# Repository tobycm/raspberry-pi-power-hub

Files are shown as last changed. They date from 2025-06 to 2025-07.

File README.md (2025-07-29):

# RP2040 + CYPD3177 Power Hub

one port (usb c) to rule them all!!! this board is designed to take a single USB-C input and negociate for your power needs. it can output 5v, 9v, 12v, or 20v at up to 3A. the usb c port is also connected to a RP2040 if you want more processing with the CYPD3177 through HPI.

## 3D render

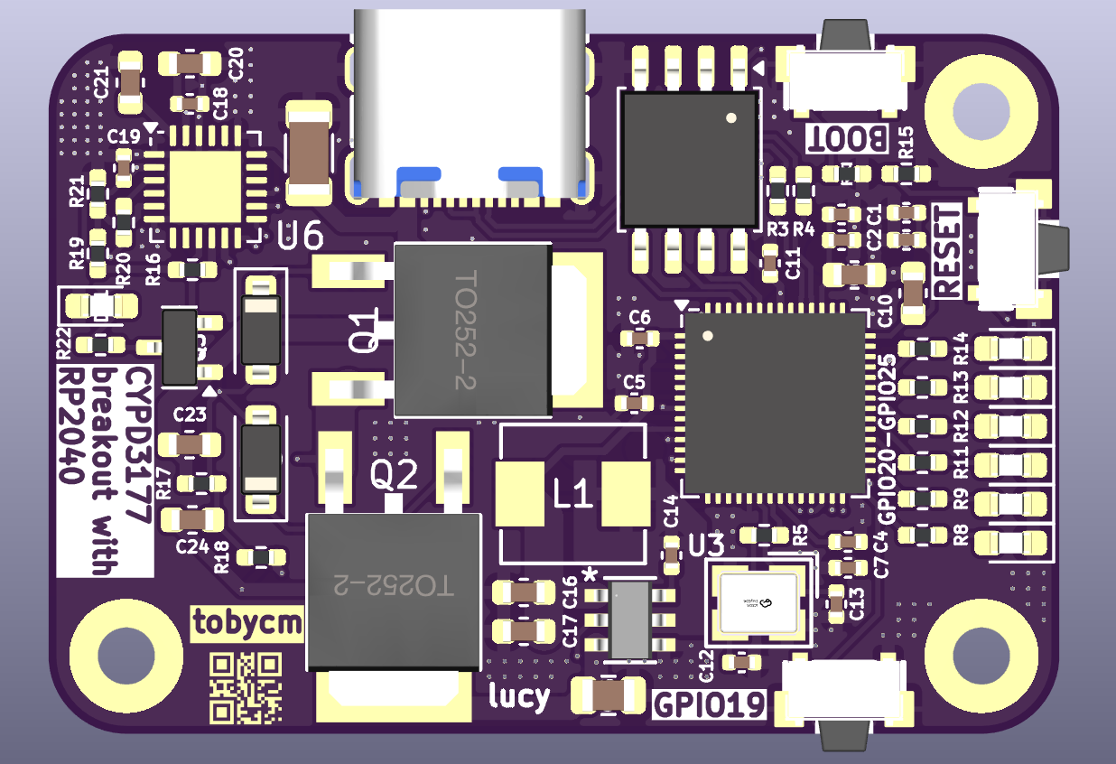
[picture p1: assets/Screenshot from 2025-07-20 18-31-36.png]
front


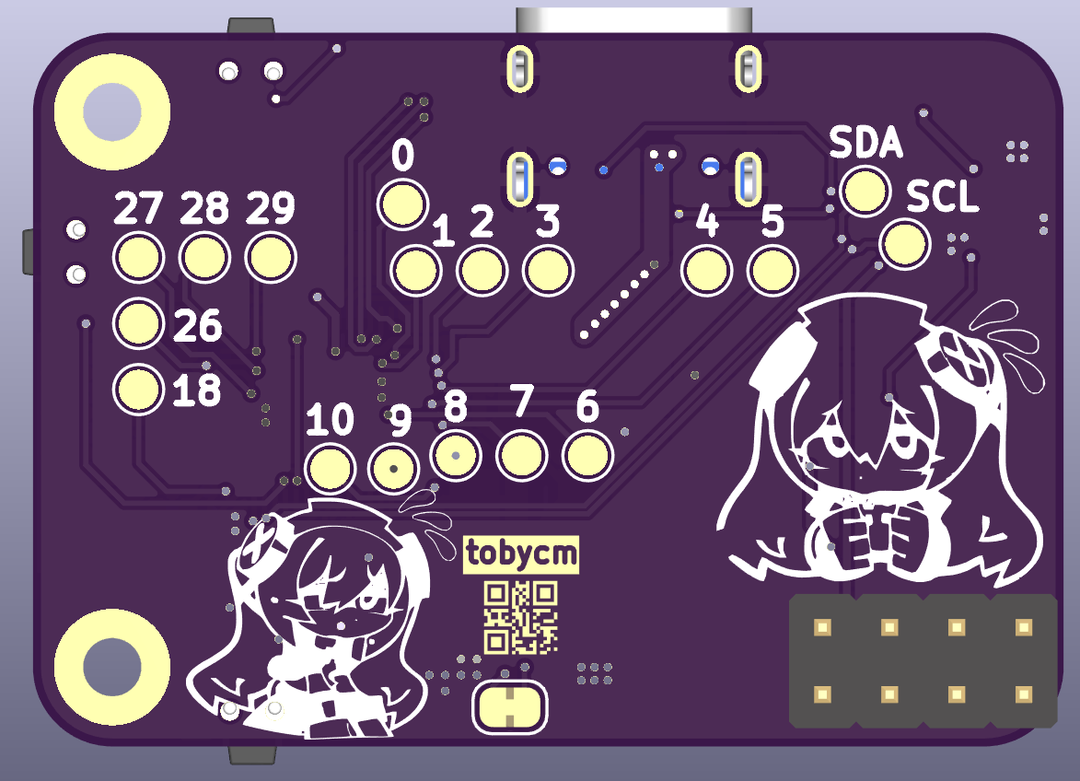
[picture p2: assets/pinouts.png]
back


## BOM

| Part Name | Quantity | Link |
| :--- | :---: | :--- |
| PCB | 1 | [JLCPCB](https://jlcpcb.com) |
| Stencil | 1 | [JLCPCB](https://jlcpcb.com) |
| RP2040 | 1 | [C2040](https://lcsc.com/product-detail/C2040.html) |
| CYPD3177-24LQ | 1 | [C5904158](https://lcsc.com/product-detail/C5904158.html) |
| W25Q32JVSS | 1 | [C82344](https://lcsc.com/product-detail/C82344.html) |
| GT-USB-7010AN | 1 | [C963370](https://lcsc.com/product-detail/C963370.html) |
| ABM8-272-T3\_C20625731 | 1 | [C20625731](https://lcsc.com/product-detail/C20625731.html) |
| TS24CA | 3 | [C393942](https://lcsc.com/product-detail/C393942.html) |
| AP63203WU-7 | 1 | [C780769](https://lcsc.com/product-detail/C780769.html) |
| Zener Diode | 2 | [C82088](https://lcsc.com/product-detail/C82088.html) |
| NPN | 1 | [C5338312](https://lcsc.com/product-detail/C5338312.html) |
| AOD409-HXY | 2 | [C6285771](https://lcsc.com/product-detail/C6285771.html) |
| Green Led | 2 | [C7496818](https://lcsc.com/product-detail/C7496818.html) |
| Amber Led | 2 | [C165983](https://lcsc.com/product-detail/C165983.html) |
| Red Led | 3 | [C965799](https://lcsc.com/product-detail/C965799.html) |
| 18pF | 2 | [C106202](https://lcsc.com/product-detail/C106202.html) |
| 100nF | 12 | [C60474](https://lcsc.com/product-detail/C60474.html) |
| 10uF | 3 | [C2762594](https://lcsc.com/product-detail/C2762594.html) |
| 1uF | 6 | [C1592](https://lcsc.com/product-detail/C1592.html) |
| 4.7uF | 1 | [C51205](https://lcsc.com/product-detail/C51205.html) |
| 4.7uH | 1 | [C41413058](https://lcsc.com/product-detail/C41413058.html) |
| 470ohm | 7 | [C25117](https://lcsc.com/product-detail/C25117.html) |
| 49.9kohm | 1 | [C25897](https://lcsc.com/product-detail/C25897.html) |
| 4.7kohm | 1 | [C25900](https://lcsc.com/product-detail/C25900.html) |
| 5.1kohm | 1 | [C25905](https://lcsc.com/product-detail/C25905.html) |
| 10kohm | 1 | [C60490](https://lcsc.com/product-detail/C60490.html) |
| 1kohm | 5 | [C106235](https://lcsc.com/product-detail/C106235.html) |
| 27ohm | 2 | [C138021](https://lcsc.com/product-detail/C138021.html) |
| Pin Headers | 1 | [C7501275](https://lcsc.com/product-detail/C7501275.html) |
| | |
| Total cost | 74.24 USD LCSC + 13.98 USD JLCPCB = 88.22 USD | |
| Soldering paste (cheaper than PCBA) | 1 | https://amazon.ca/dp/B0BLSJQPR6 |
| Total cost with soldering paste | 88.22 USD + 19.59 CAD = 102.43 USD | |

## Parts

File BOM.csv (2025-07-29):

Part Name | Quantity | Link
PCB | 1 | https://jlcpcb.com
Stencil | 1 | https://jlcpcb.com
RP2040 | 1 | https://lcsc.com/product-detail/C2040.html
CYPD3177-24LQ | 1 | https://lcsc.com/product-detail/C5904158.html
W25Q32JVSS | 1 | https://lcsc.com/product-detail/C82344.html
GT-USB-7010AN | 1 | https://lcsc.com/product-detail/C963370.html
ABM8-272-T3_C20625731 | 1 | https://lcsc.com/product-detail/C20625731.html
TS24CA | 3 | https://lcsc.com/product-detail/C393942.html
AP63203WU-7 | 1 | https://lcsc.com/product-detail/C780769.html
Zener Diode | 2 | https://lcsc.com/product-detail/C82088.html
NPN | 1 | https://lcsc.com/product-detail/C5338312.html
AOD409-HXY | 2 | https://lcsc.com/product-detail/C6285771.html
Green Led | 2 | https://lcsc.com/product-detail/C7496818.html
Amber Led | 2 | https://lcsc.com/product-detail/C165983.html
Red Led | 3 | https://lcsc.com/product-detail/C965799.html
18pF | 2 | https://lcsc.com/product-detail/C106202.html
100nF | 12 | https://lcsc.com/product-detail/C60474.html
10uF | 3 | https://lcsc.com/product-detail/C2762594.html
1uF | 6 | https://lcsc.com/product-detail/C1592.html
4.7uF | 1 | https://lcsc.com/product-detail/C51205.html
4.7uH | 1 | https://lcsc.com/product-detail/C41413058.html
470ohm | 7 | https://lcsc.com/product-detail/C25117.html
49.9kohm | 1 | https://lcsc.com/product-detail/C25897.html
4.7kohm | 1 | https://lcsc.com/product-detail/C25900.html
5.1kohm | 1 | https://lcsc.com/product-detail/C25905.html
10kohm | 1 | https://lcsc.com/product-detail/C60490.html
1kohm | 5 | https://lcsc.com/product-detail/C106235.html
27ohm | 2 | https://lcsc.com/product-detail/C138021.html
Pin Headers | 1 | https://lcsc.com/product-detail/C7501275.html

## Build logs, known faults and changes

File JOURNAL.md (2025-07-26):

---
author: tobycm
created_at: "2025-06-25"
description: a usb c power hub to power all of my raspberry pis (and other usb c devices!)
title: Raspberry Pi Power Hub
---

# Raspberry Pi Power Hub

## Jun 25, 2025 | 12:00 - 16:00 | Init

since i made devices with usb c pd stuff before, im going with cypd3175 and cypd3177 ICs for this :3

https://g.co/gemini/share/f052dd489182

i love gemini, lots of good researching and i can just compare and decide

after lots of consulting, i ended up with:

- 4 cypd3175 ics, for a total of 4 usb c and 4 usb a ports
- 1 cypd3177 ic
- 1 rp2040 ic for the main brain of the device 🔥🔥🔥

time to research for parts on lcsc, and wire them up in kicad

- usb c receptacle: [https://lcsc.com/product-detail/USB-Connectors_G-Switch-GT-USB-7010AN_C963370.html](https://lcsc.com/product-detail/USB-Connectors_G-Switch-GT-USB-7010AN_C963370.html)
- cypd3175: [https://lcsc.com/product-detail/USB-Converters_Infineon-Cypress-Semicon-CYPD3175-24LQXQT_C2952419.html](https://lcsc.com/product-detail/USB-Converters_Infineon-Cypress-Semicon-CYPD3175-24LQXQT_C2952419.html)
- cypd3177: [https://lcsc.com/product-detail/Power-Management-Specialized_Infineon-Technologies-CYPD3177-24LQXQT_C5904158.html](https://lcsc.com/product-detail/Power-Management-Specialized_Infineon-Technologies-CYPD3177-24LQXQT_C5904158.html)
- buck converter: [https://lcsc.com/product-detail/DC-DC-Converters_Tokmas-TPS54561DPRR-TOKMAS_C7589231.html](https://lcsc.com/product-detail/DC-DC-Converters_Tokmas-TPS54561DPRR-TOKMAS_C7589231.html)
- rp2040: [https://lcsc.com/product-detail/Microcontrollers-MCU-MPU-SOC_Raspberry-Pi-RP2040_C2040.html](https://lcsc.com/product-detail/Microcontrollers-MCU-MPU-SOC_Raspberry-Pi-RP2040_C2040.html)

## 21:00 - 22:50 | copied rp2040 wiring from previous board

with the new diode and no more latching button xd.

lots of time spent on finding parts on LCSC

## Jun 29, 2025 | 17:15 - 21:45 | wiring up cypd3177 and fix up rp2040

the datasheet reference schematic is the best place to start, as they have values that the manufacturer tested and recommends.

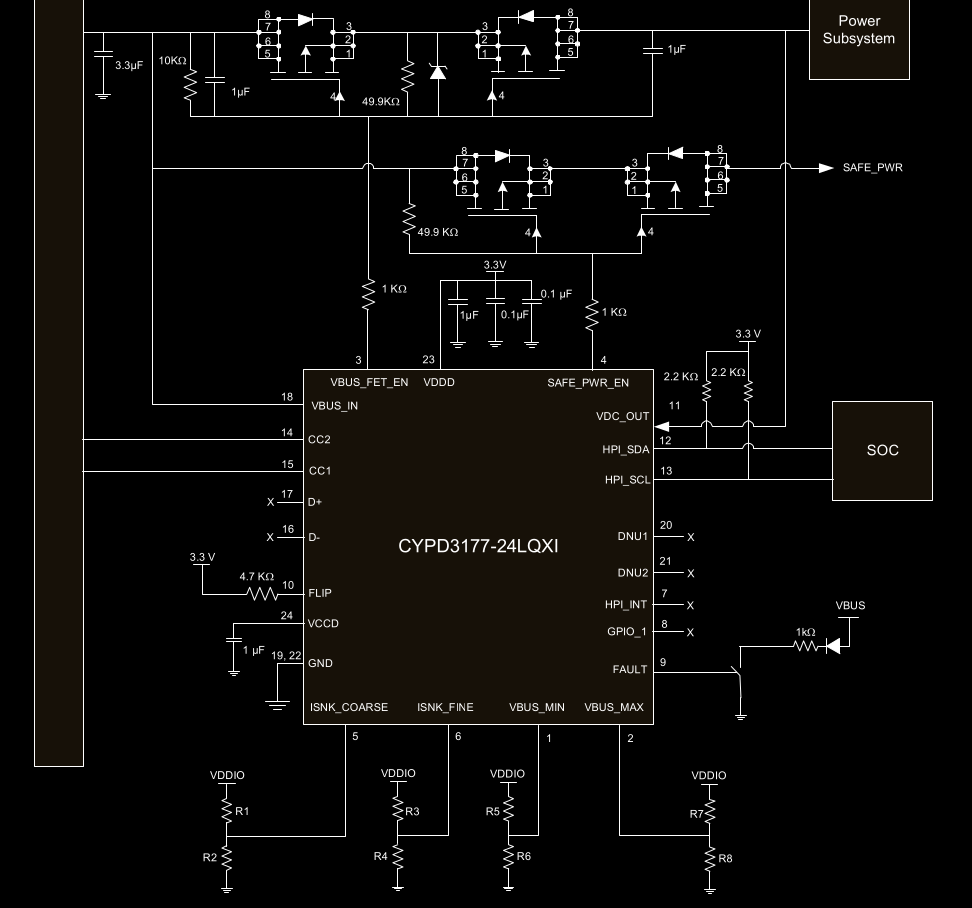
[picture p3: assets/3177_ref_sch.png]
datasheet reference schematic


after some questions and answers with Google Gemini, i learned that:

- the 2 mosfets facing each other are for reverse current protection, if this device is disconnected from the power source, it will not allow current to flow back into the power source, causing undefined behavior.
- safe_pwr always provides 5V, so that is nice to power microcontrollers and other devices that need 5V always on.
- table 2, 3, and 4 in the datasheet helps with choosing resistor values to set the desired voltage range and min current limit.

after a bit more chatting with Google Gemini:

- trying to optimize for efficiency: we went with a better buck converter than the XXL1509-5.0 with 83% for a Silergy brand buck converter, which has ~92% efficiency. a lot better.

because the cypd3175 can support an additional 5V usb output, i will supply 2 type a port with the Silergy 6A 5V buck converter

too much shopping, i should start wiring this up in kicad 💀

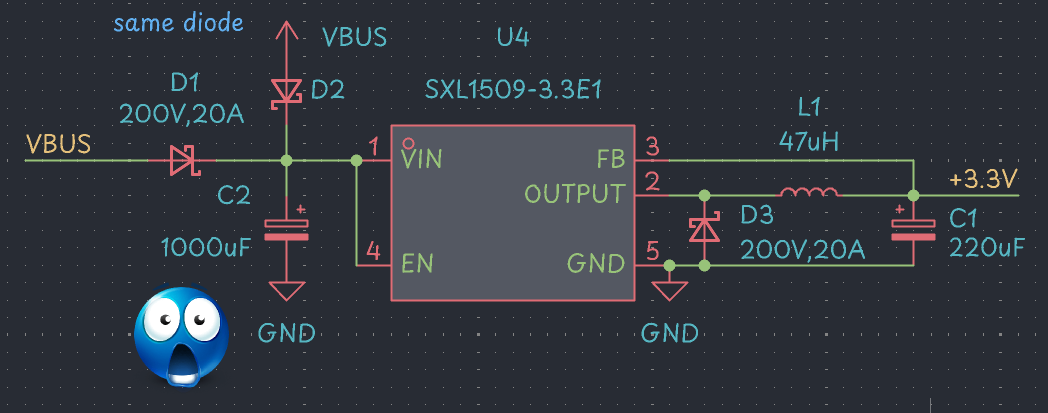
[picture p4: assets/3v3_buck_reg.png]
peak schematic


literally peak

## Jul 19, 2025 | 16:00 - 20:00 | finishing wiring up cypd3177

small life update: i got a new job :D downside is i have less time to work on this project :C

apparently lots of MOSFETs have max Vgs of 20V, so i had to find a zener diode to clamp the gate voltage to 18V, so that the MOSFETs don't get damaged.

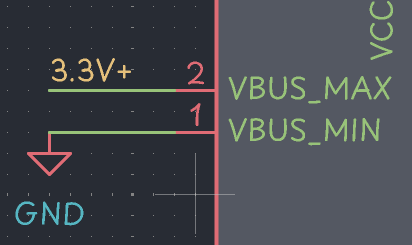
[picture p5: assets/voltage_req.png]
requesting 5V min and 20V max


to request 5V min and 20V max

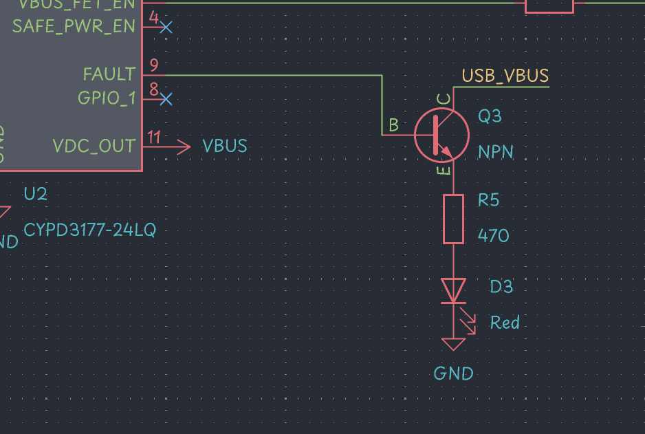
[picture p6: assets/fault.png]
fault led


added a fault indicator LED :D

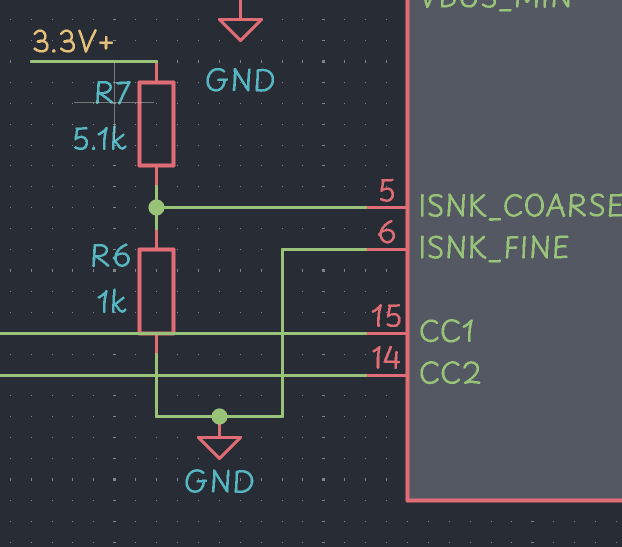
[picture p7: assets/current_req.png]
current request setup


to request at least 1A of current :D

## Jul 20, 2025 | 12:00 - 18:00 | laying out the board

i think i will make smaller cypd3175 modules, so this board will only have the cypd3177 and rp2040, and the buck converter for 3.3V

front 3d
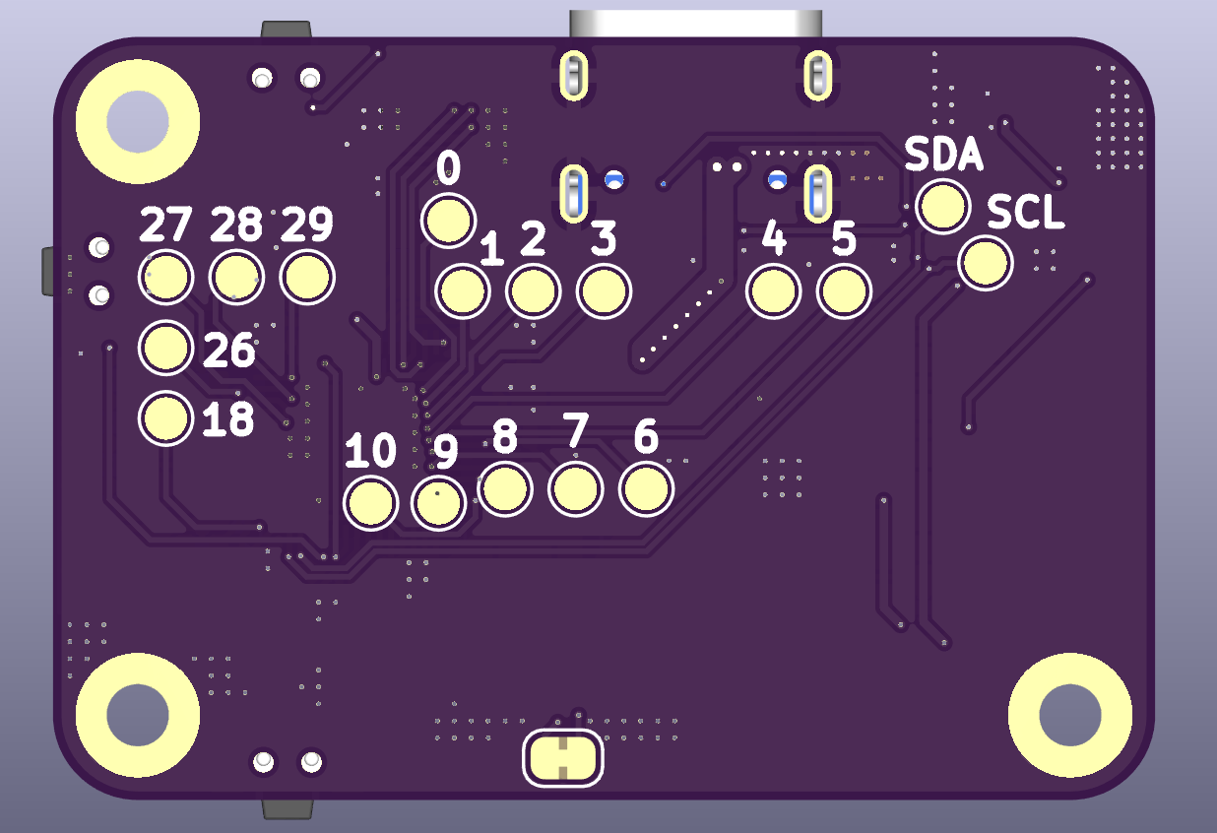
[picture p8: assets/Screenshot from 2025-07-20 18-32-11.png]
back 3d


FINALLY DONE WOOHOO! time to add a bunch of art and make it look nice :D

## Jul 26, 2025 | 13:20 - 15:00 | im cooked

i just realized that my via size is too small, so i have to fix all of that 😭😭😭😭😭😭

drc

oof

also i forgot that this is meant to be kinda like a breakout, and i forgot to breakout the power outputs 💀💀

good drc

lets gooooooooo

pinouts

pinouts added too! done!

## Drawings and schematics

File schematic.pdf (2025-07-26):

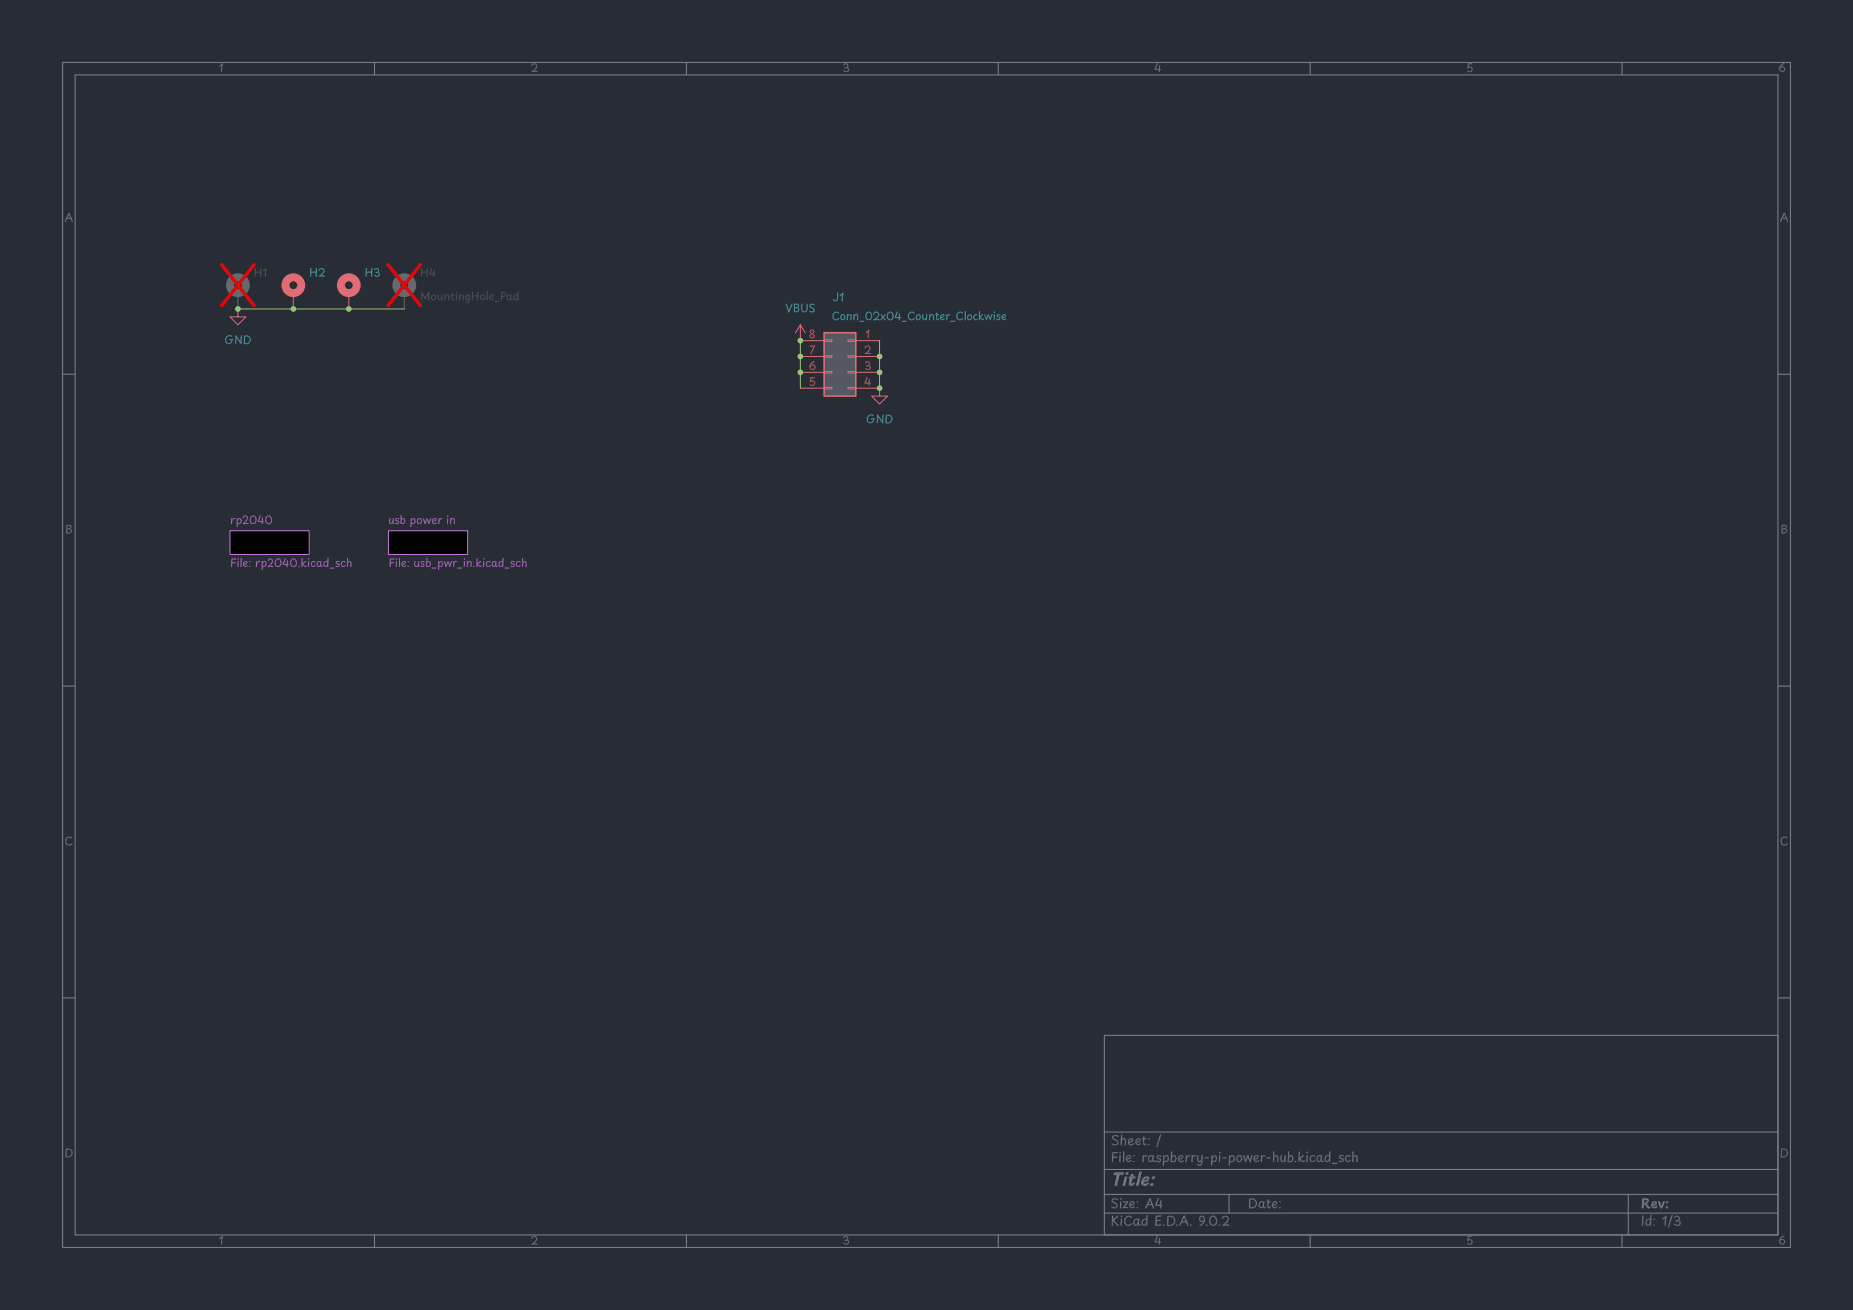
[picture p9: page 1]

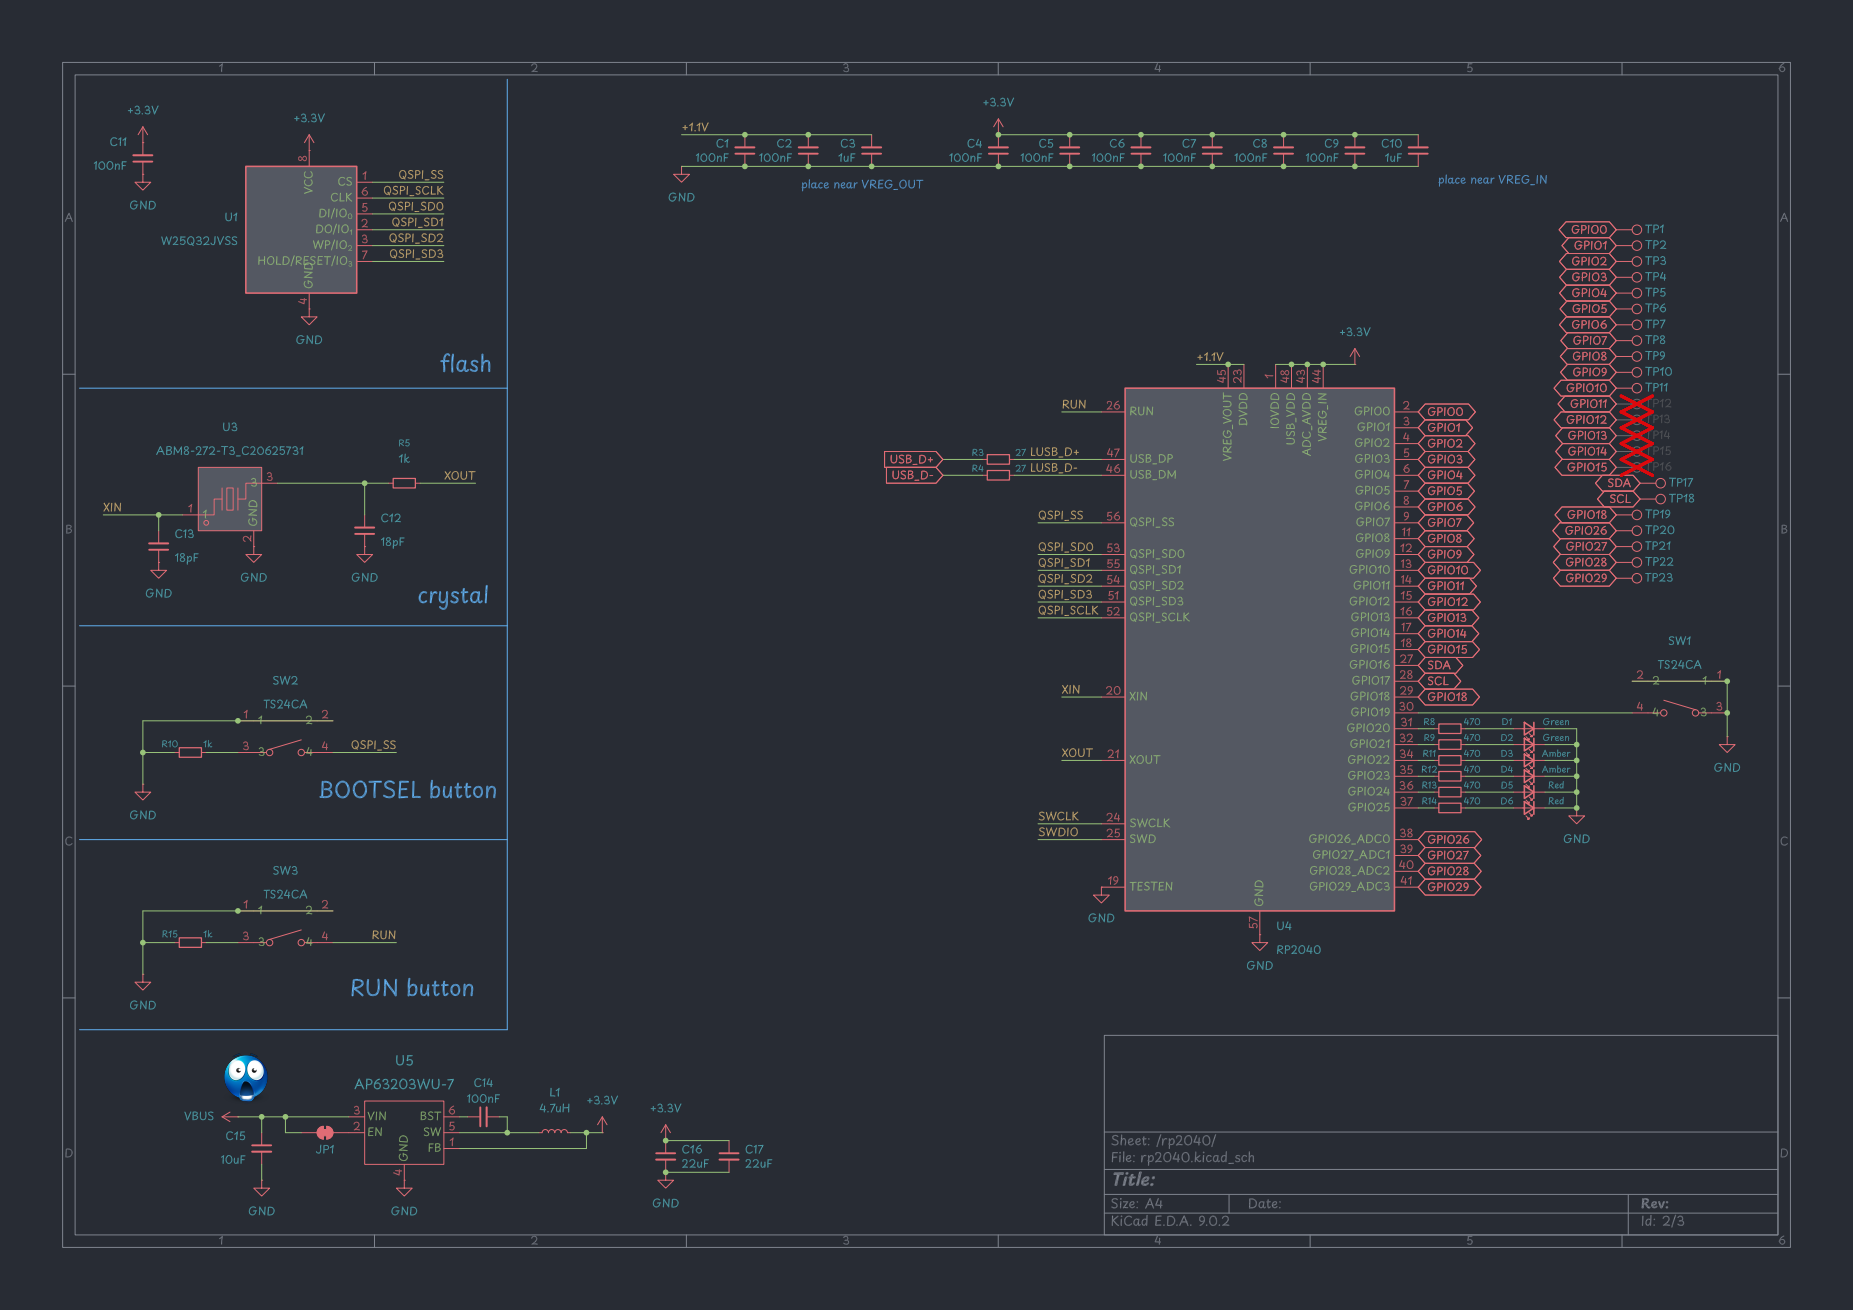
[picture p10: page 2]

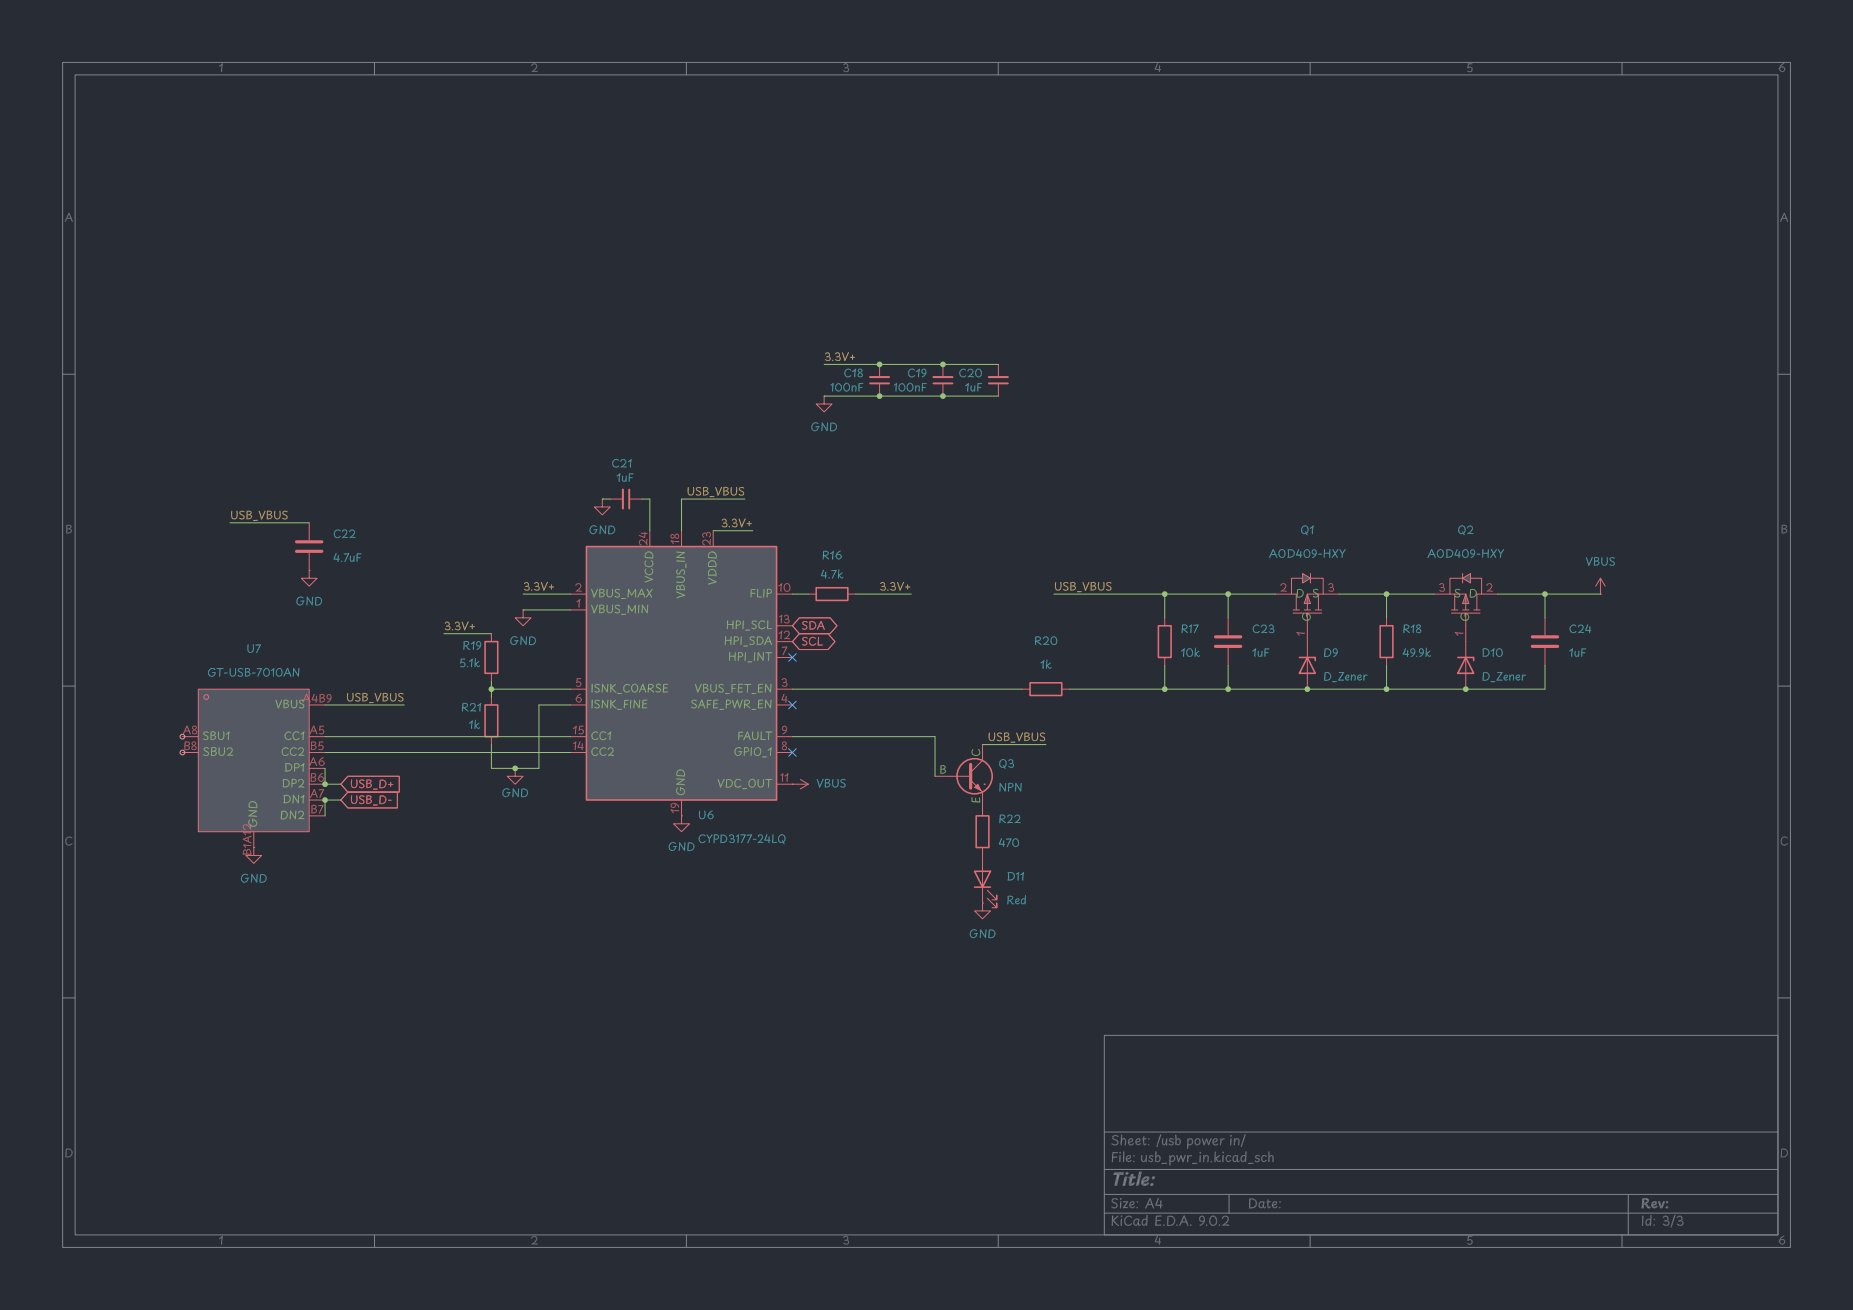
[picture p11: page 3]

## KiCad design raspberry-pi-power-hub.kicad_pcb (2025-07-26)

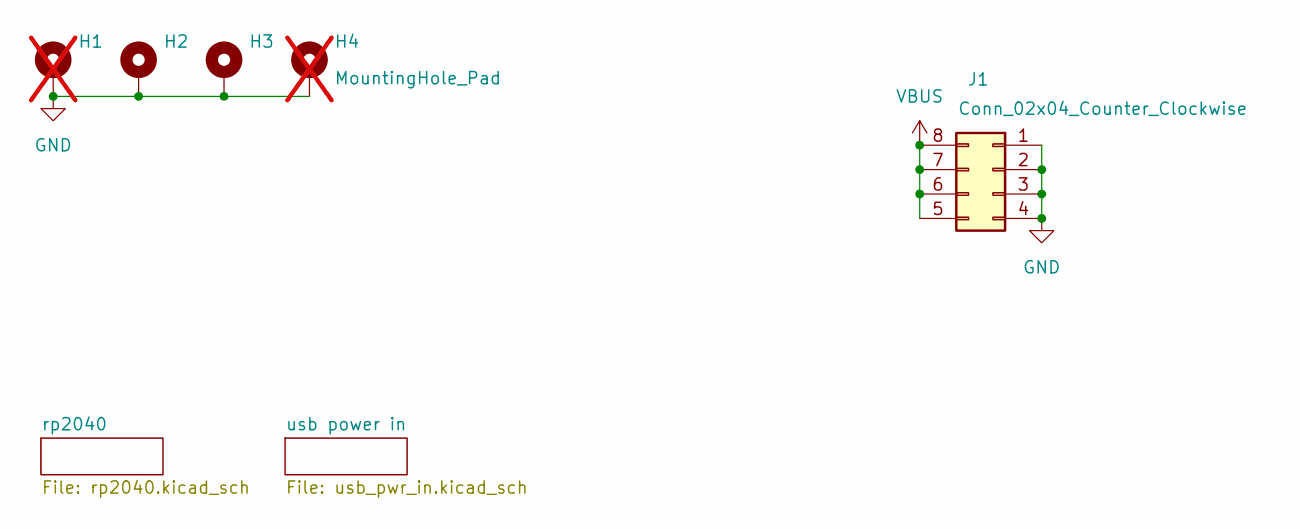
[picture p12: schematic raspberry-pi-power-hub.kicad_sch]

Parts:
H1, H4: MountingHole_Pad; MountingHole_2.2mm_M2_Pad; not fitted
H2, H3: MountingHole_Pad; MountingHole_2.2mm_M2_Pad
J1: Conn_02x04_Counter_Clockwise; PinHeader_2x04_P2.54mm_Vertical

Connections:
GND: H1.1, H2.1, H3.1, H4.1, J1.1, J1.2, J1.3, J1.4; also elsewhere on the board
VBUS: J1.5, J1.6, J1.7, J1.8; also elsewhere on the board

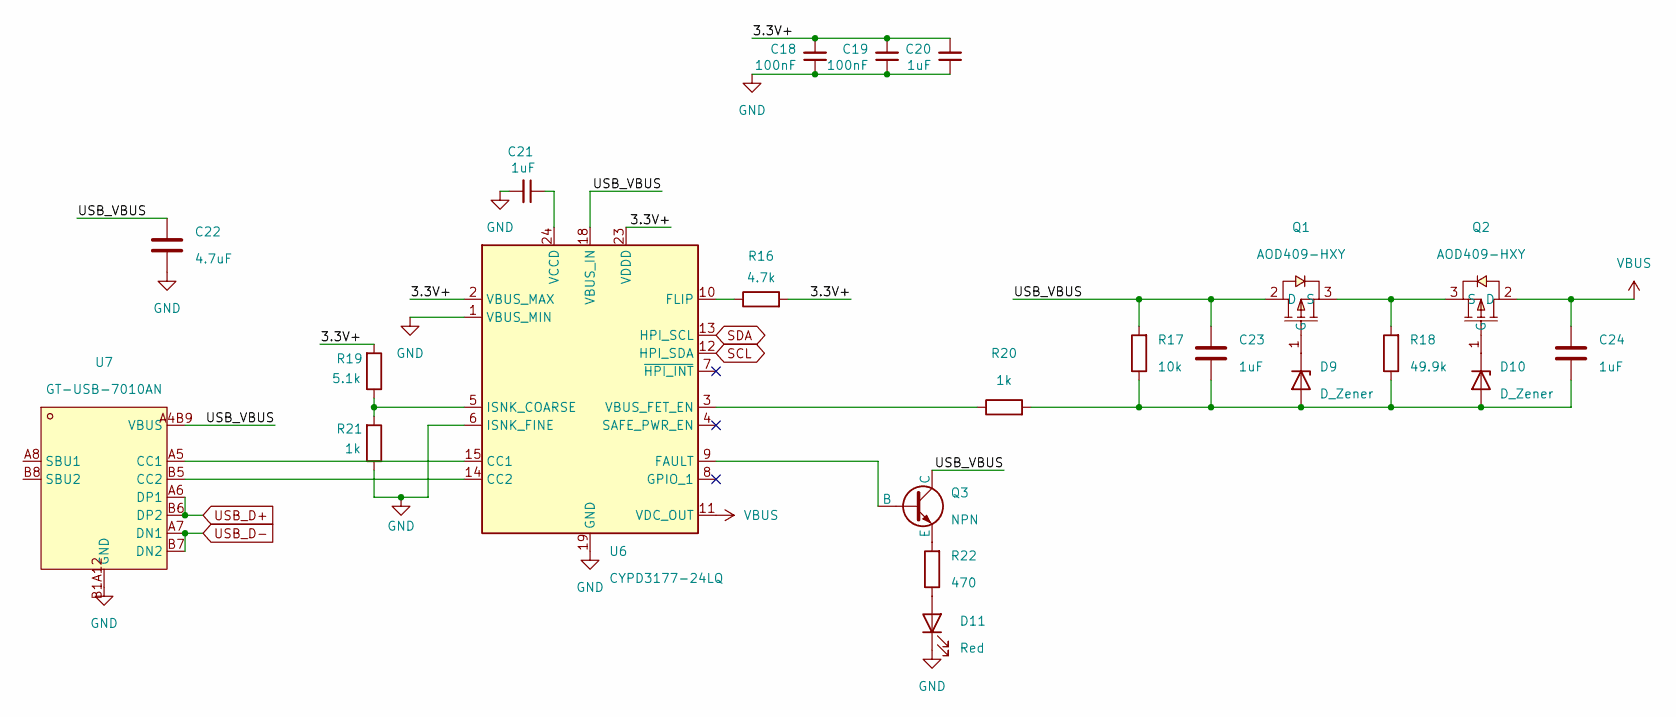
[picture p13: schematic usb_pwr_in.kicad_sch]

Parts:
C18, C19: 100nF; C_0402_1005Metric
C20, C21, C23, C24: 1uF; C_0603_1608Metric
C22: 4.7uF; C_1206_3216Metric
D9, D10: D_Zener; D_SOD-123
D11: Red; LED_0603_1608Metric_Pad1.05x0.95mm_HandSolder
Q1, Q2: AOD409-HXY; TO-252-2_L6.6-W6.1-P4.57-LS9.9-TL-CW; LCSC Part C6285771
Q3: NPN; SOT-23
R16: 4.7k; R_0402_1005Metric_Pad0.72x0.64mm_HandSolder
R17: 10k; R_0402_1005Metric_Pad0.72x0.64mm_HandSolder
R18: 49.9k; R_0402_1005Metric_Pad0.72x0.64mm_HandSolder
R19: 5.1k; R_0402_1005Metric_Pad0.72x0.64mm_HandSolder
R20, R21: 1k; R_0402_1005Metric_Pad0.72x0.64mm_HandSolder
R22: 470; R_0402_1005Metric_Pad0.72x0.64mm_HandSolder
U6: CYPD3177-24LQ; QFN-24-1EP_4x4mm_P0.5mm_EP2.75x2.75mm
U7: GT-USB-7010AN; USB-SMD_GT-USB-7010AN; LCSC Part C963370

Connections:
/usb power in/3.3V+: C18.2, C19.2, C20.2, R16.2, R19.2, U6.2 (VBUS_MAX), U6.23 (VDDD)
/usb power in/USB_VBUS: C22.1, C23.1, Q1.2 (D), Q3.1 (C), R17.2, U6.18 (VBUS_IN), U7.A4B9 (VBUS), U7.B4A9 (VBUS)
GND: C18.1, C19.1, C20.1, C21.2, C22.2, D11.1 (K), R21.1, U6.1 (VBUS_MIN), U6.6 (ISNK_FINE), U6.19 (GND), U6.22 (GND), U6.25 (GND), U7.13 (GND), U7.14 (GND), U7.15 (GND), U7.16 (GND), U7.A1B12 (GND), U7.B1A12 (GND); also elsewhere on the board
unnamed: D9.1 (K), Q1.1 (G)
unnamed: C23.2, C24.2, D9.2 (A), D10.2 (A), R17.1, R18.1, R20.2
unnamed: D10.1 (K), Q2.1 (G)
unnamed: D11.2 (A), R22.1
unnamed: Q1.3 (S), Q2.3 (S), R18.2
unnamed: Q3.2 (B), U6.9 (FAULT)
unnamed: Q3.3 (E), R22.2
unnamed: U6.15 (CC1), U7.A5 (CC1)
unnamed: U6.14 (CC2), U7.B5 (CC2)
unnamed: R16.1, U6.10 (FLIP)
unnamed: R19.1, R21.2, U6.5 (ISNK_COARSE)
unnamed: R20.1, U6.3 (VBUS_FET_EN)
unnamed: C21.1, U6.24 (VCCD)
SCL: U6.12 (HPI_SDA); also elsewhere on the board
SDA: U6.13 (HPI_SCL); also elsewhere on the board
USB_D+: U7.A6 (DP1), U7.B6 (DP2); also elsewhere on the board
USB_D-: U7.A7 (DN1), U7.B7 (DN2); also elsewhere on the board
VBUS: C24.1, Q2.2 (D), U6.11 (VDC_OUT); also elsewhere on the board

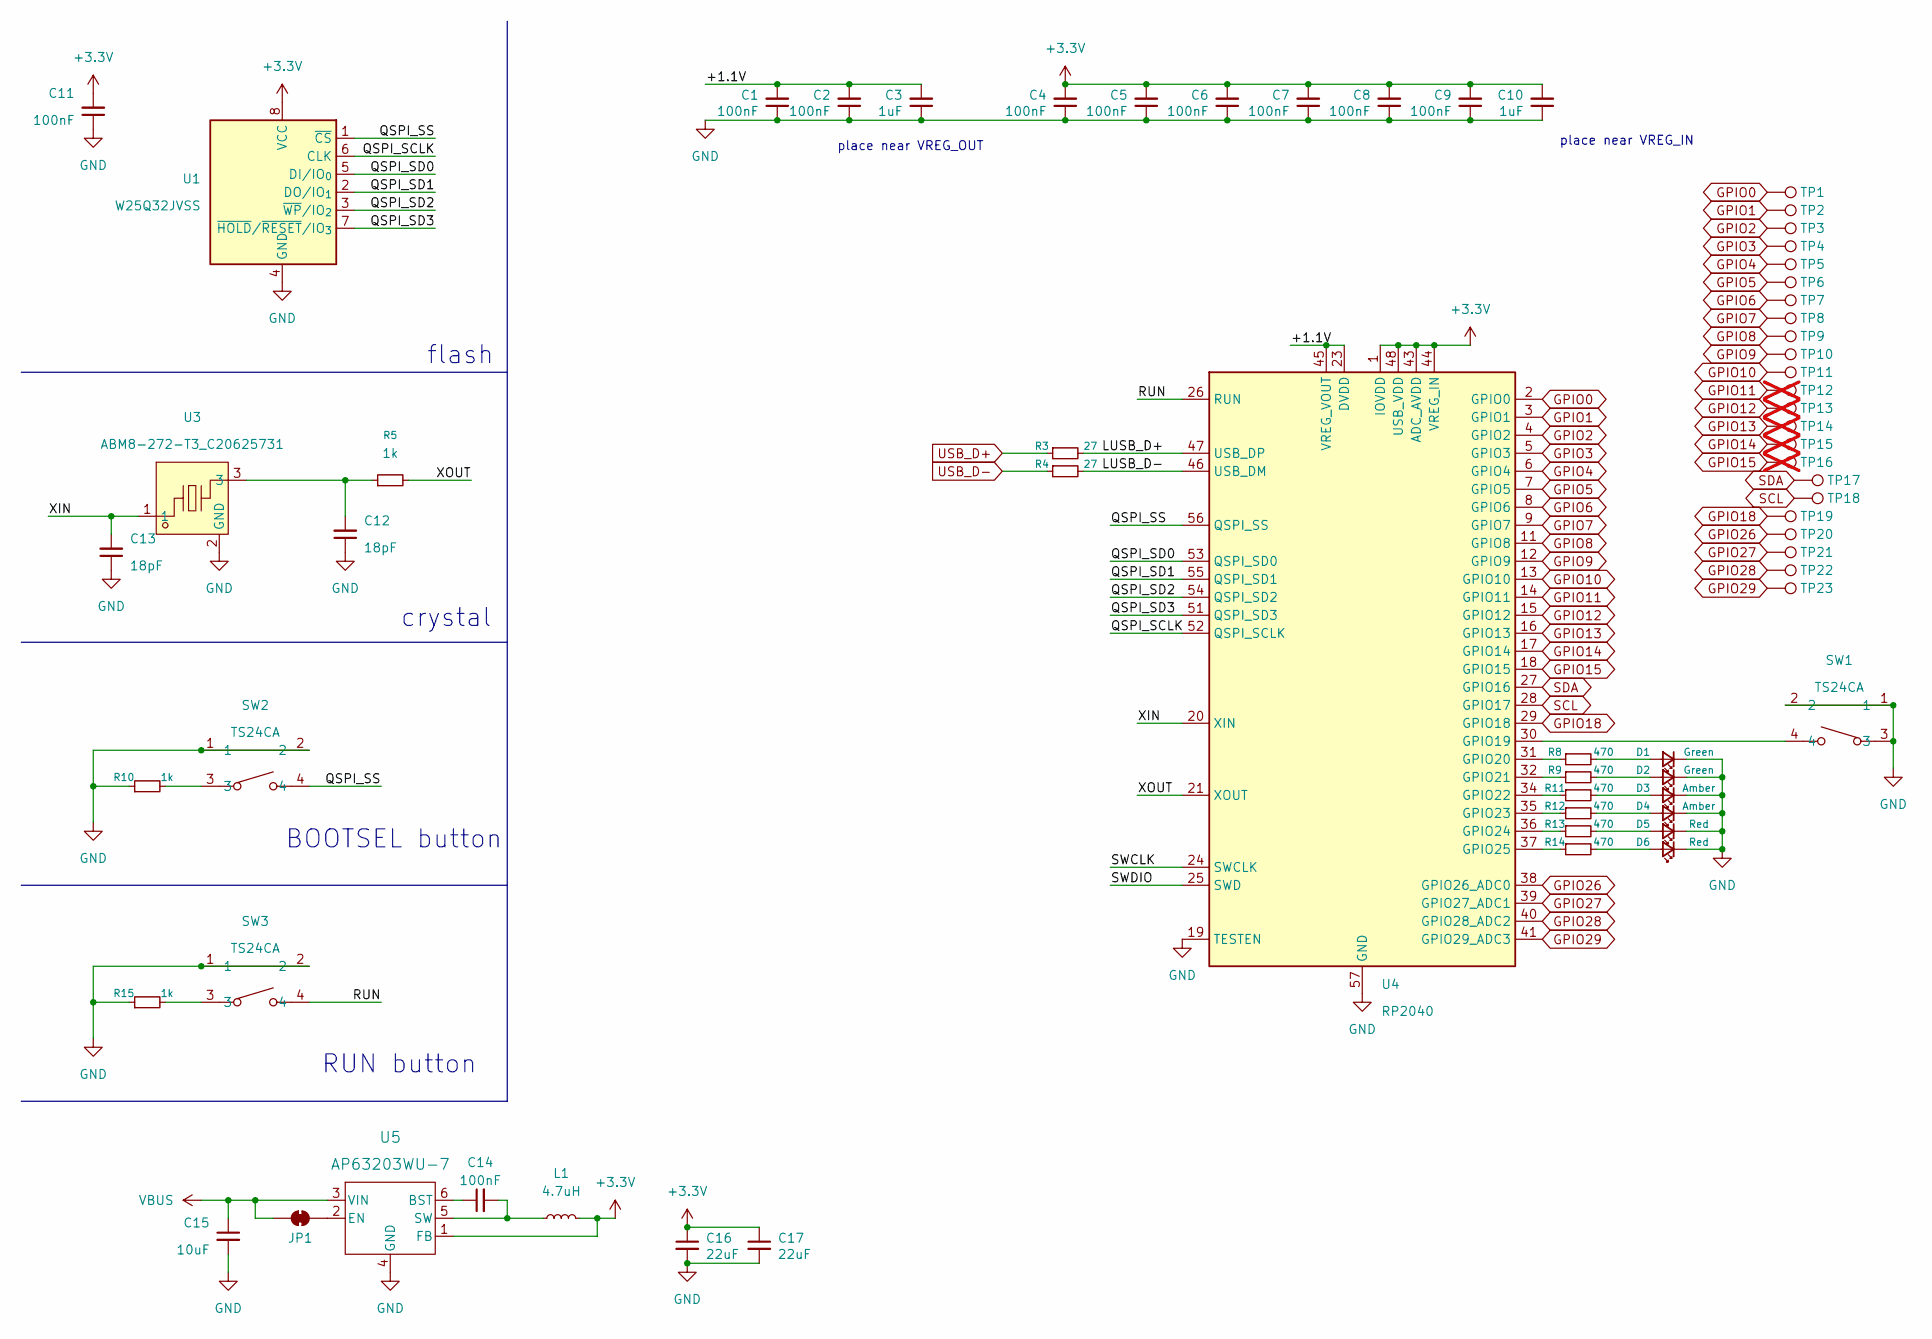
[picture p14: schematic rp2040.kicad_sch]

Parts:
C1, C2, C4, C5, C6, C7, C8, C9, C11, C14: 100nF; C_0402_1005Metric
C3, C10: 1uF; C_0603_1608Metric
C12, C13: 18pF; C_0402_1005Metric
C15: 10uF; C_0805_2012Metric
C16, C17: 22uF; C_0603_1608Metric
D1, D2: Green; LED_0603_1608Metric_Pad1.05x0.95mm_HandSolder
D3, D4: Amber; LED_0603_1608Metric_Pad1.05x0.95mm_HandSolder
D5, D6: Red; LED_0603_1608Metric_Pad1.05x0.95mm_HandSolder
JP1: SolderJumper_2_Bridged; SolderJumper-2_P1.3mm_Bridged_RoundedPad1.0x1.5mm
L1: 4.7uH; IND-SMD_L5.4-W5.2_CMLE051E
R3, R4: 27; R_0402_1005Metric_Pad0.72x0.64mm_HandSolder
R5, R10, R15: 1k; R_0402_1005Metric_Pad0.72x0.64mm_HandSolder
R8, R9, R11, R12, R13, R14: 470; R_0402_1005Metric_Pad0.72x0.64mm_HandSolder
SW1, SW2, SW3: TS24CA; SW-SMD_TS24CA; LCSC Part C393942
TP1, TP2, TP3, TP4, TP5, TP6, TP7, TP8, TP9, TP10, TP11, TP17, TP18, TP19, TP20, TP21, TP22, TP23: TestPoint; TestPoint_Pad_D1.5mm
TP12, TP13, TP14, TP15, TP16: TestPoint; TestPoint_Pad_D1.5mm; not fitted
U1: W25Q32JVSS; SOIC-8_5.3x5.3mm_P1.27mm
U3: ABM8-272-T3_C20625731; CRYSTAL-SMD_4P-L3.2-W2.5-BL; LCSC Part C20625731
U4: RP2040; QFN-56-1EP_7x7mm_P0.4mm_EP3.2x3.2mm
U5: AP63203WU-7; AP63203WU-7_DIO

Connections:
+3.3V: C4.2, C5.2, C6.2, C7.2, C8.2, C9.2, C10.2, C11.2, C16.1, C17.1, L1.2, U1.8 (VCC), U4.1 (IOVDD), U4.10 (IOVDD), U4.22 (IOVDD), U4.33 (IOVDD), U4.42 (IOVDD), U4.43 (ADC_AVDD), U4.44 (VREG_IN), U4.48 (USB_VDD), U4.49 (IOVDD), U5.1 (FB)
/rp2040/+1.1V: C1.2, C2.2, C3.2, U4.23 (DVDD), U4.45 (VREG_VOUT), U4.50 (DVDD)
/rp2040/LUSB_D+: R3.2, U4.47 (USB_DP)
/rp2040/LUSB_D-: R4.2, U4.46 (USB_DM)
/rp2040/QSPI_SCLK: U1.6 (CLK), U4.52 (QSPI_SCLK)
/rp2040/QSPI_SD0: U1.5 (DI/IO_{0}), U4.53 (QSPI_SD0)
/rp2040/QSPI_SD1: U1.2 (DO/IO_{1}), U4.55 (QSPI_SD1)
/rp2040/QSPI_SD2: U1.3 (~WP/IO_{2}), U4.54 (QSPI_SD2)
/rp2040/QSPI_SD3: U1.7 (~HOLD/~RESET/IO_{3}), U4.51 (QSPI_SD3)
/rp2040/QSPI_SS: SW2.4, U1.1 (~CS), U4.56 (QSPI_SS)
/rp2040/RUN: SW3.4, U4.26 (RUN)
/rp2040/SWCLK: U4.24 (SWCLK)
/rp2040/SWDIO: U4.25 (SWD)
/rp2040/XIN: C13.2, U3.1, U4.20 (XIN)
/rp2040/XOUT: R5.2, U4.21 (XOUT)
GND: C1.1, C2.1, C3.1, C4.1, C5.1, C6.1, C7.1, C8.1, C9.1, C10.1, C11.1, C12.1, C13.1, C15.2, C16.2, C17.2, D1.1 (K), D2.1 (K), D3.1 (K), D4.1 (K), D5.1 (K), D6.1 (K), R10.1, R15.1, SW1.1, SW1.2, SW1.3, SW2.1, SW2.2, SW3.1, SW3.2, U1.4 (GND), U3.2 (GND), U3.4 (GND), U4.19 (TESTEN), U4.57 (GND), U5.4 (GND); also elsewhere on the board
GPIO0: TP1.1, U4.2 (GPIO0)
GPIO1: TP2.1, U4.3 (GPIO1)
GPIO2: TP3.1, U4.4 (GPIO2)
GPIO3: TP4.1, U4.5 (GPIO3)
GPIO4: TP5.1, U4.6 (GPIO4)
GPIO5: TP6.1, U4.7 (GPIO5)
GPIO6: TP7.1, U4.8 (GPIO6)
GPIO7: TP8.1, U4.9 (GPIO7)
GPIO8: TP9.1, U4.11 (GPIO8)
GPIO9: TP10.1, U4.12 (GPIO9)
GPIO10: TP11.1, U4.13 (GPIO10)
GPIO11: TP12.1, U4.14 (GPIO11)
GPIO12: TP13.1, U4.15 (GPIO12)
GPIO13: TP14.1, U4.16 (GPIO13)
GPIO14: TP15.1, U4.17 (GPIO14)
GPIO15: TP16.1, U4.18 (GPIO15)
GPIO18: TP19.1, U4.29 (GPIO18)
GPIO26: TP20.1, U4.38 (GPIO26_ADC0)
GPIO27: TP21.1, U4.39 (GPIO27_ADC1)
GPIO28: TP22.1, U4.40 (GPIO28_ADC2)
GPIO29: TP23.1, U4.41 (GPIO29_ADC3)
unnamed: C12.2, R5.1, U3.3
unnamed: D1.2 (A), R8.2
unnamed: D2.2 (A), R9.2
unnamed: D3.2 (A), R11.2
unnamed: D4.2 (A), R12.2
unnamed: D5.2 (A), R13.2
unnamed: D6.2 (A), R14.2
unnamed: JP1.2 (B), U5.2 (EN)
unnamed: R10.2, SW2.3
unnamed: R15.2, SW3.3
unnamed: SW1.4, U4.30 (GPIO19)
unnamed: R8.1, U4.31 (GPIO20)
unnamed: R9.1, U4.32 (GPIO21)
unnamed: R11.1, U4.34 (GPIO22)
unnamed: R12.1, U4.35 (GPIO23)
unnamed: R13.1, U4.36 (GPIO24)
unnamed: R14.1, U4.37 (GPIO25)
unnamed: C14.1, U5.6 (BST)
unnamed: C14.2, L1.1, U5.5 (SW)
SCL: TP18.1, U4.28 (GPIO17); also elsewhere on the board
SDA: TP17.1, U4.27 (GPIO16); also elsewhere on the board
USB_D+: R3.1; also elsewhere on the board
USB_D-: R4.1; also elsewhere on the board
VBUS: C15.1, JP1.1 (A), U5.3 (VIN); also elsewhere on the board

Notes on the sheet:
place near VREG_OUT
place near VREG_IN
RUN button
crystal
flash
BOOTSEL button

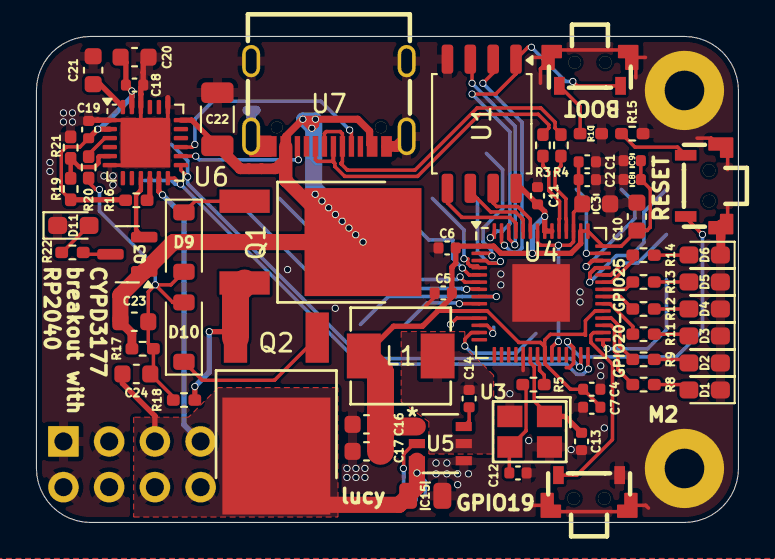
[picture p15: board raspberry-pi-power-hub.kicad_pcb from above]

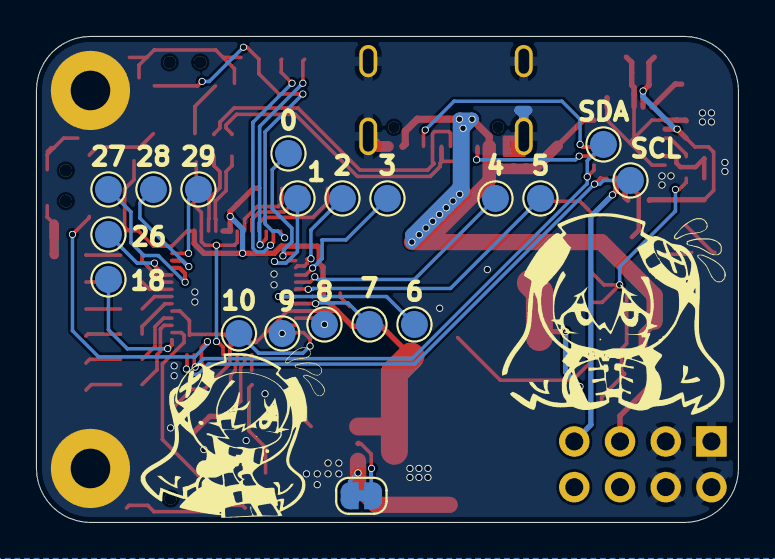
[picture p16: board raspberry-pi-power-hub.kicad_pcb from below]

Board: 2 copper layers, 39.0 x 27.0 mm, 86 parts (20 on the bottom side), 69 nets.

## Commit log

2025-06-25 getting started :fire:
    [raspberry-pi-power-hub.kicad_pcb, raspberry-pi-power-hub.kicad_sch]
2025-06-27 small rp2040 changes and the cypd3177
    [raspberry-pi-power-hub.kicad_sch, rp2040.kicad_sch, usb_pwr_in.kicad_sch]
2025-06-30 peak schematic
    [rp2040.kicad_sch, usb_pwr_in.kicad_sch]
2025-07-21 finished pcb routing yay
    [raspberry-pi-power-hub.kicad_pcb, raspberry-pi-power-hub.kicad_sch, rp2040.kicad_sch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]
2025-07-26 fixed via size woohoo!
    [raspberry-pi-power-hub.kicad_pcb, raspberry-pi-power-hub.kicad_sch]
2025-07-26 add bom
    [BOM.csv, raspberry-pi-power-hub.kicad_pcb]
2025-07-28 add total cost
    [BOM.csv]
2025-07-29 add stencil
    [BOM.csv]
2025-07-29 update bom with shipping and soldering paste
